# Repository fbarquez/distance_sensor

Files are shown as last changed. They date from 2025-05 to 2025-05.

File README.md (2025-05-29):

# Ultrasonic Distance Sensor System – Abstandssensor

## Usage Notice

This project was developed as part of the module “Information Technology / Networked Systems” in the Bachelor's program in Information and Communication Engineering.

- Repository is archived and read-only.
- Not licensed for reuse, redistribution, or modification.
- For demonstration and educational reference only.
- Licensed under **UNLICENSED**.

> Developed by **Fbarquez** - HTW Berlin, 2021

---

## About the Project

This project is a **microcontroller-based distance measuring system** designed to support social distancing during the COVID-19 pandemic. The sensor system detects nearby objects using **ultrasound technology** and triggers **visual and acoustic alerts** when the safety distance is not maintained.

> **Main goal:** Help individuals monitor and maintain the recommended 1.5–2 meters distance to prevent virus transmission.

---

## Media Preview

### [▶ Watch Demo Video](https://www.dropbox.com/scl/fi/pl3xh61fnlcbmjqz21ddf/Abstandssensor_video_FB.mp4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)

> A live demo showing the behavior of the sensor system in real conditions.

---

## Project Objectives

- Measure distances in real-time using the **HC-SR04 ultrasonic sensor**
- Visually indicate proximity using **LEDs** (green = safe, red = warning)
- Trigger **buzzer** alert when distance is dangerously short
- Display distance on a **20x4 LCD display**
- **Transmit data via Bluetooth** to a mobile app
- Provide a **portable, reliable, and affordable** prevention tool

---

## Hardware Overview

| Component | Description |
|---|---|
| PIC16F1936 | 8-bit microcontroller (main control unit) |
| LCD 20x4 | Visual distance output |
| HC-SR04 | Ultrasonic distance sensor |
| LEDs | Red (short), Green (safe) alerts |
| Buzzer | Audio alert for danger distance |
| HC-05 Bluetooth Module | Wireless transmission to Android |
| External Power Supply  | 5V regulated |

> Schematics and PCB were designed using **EAGLE** software.

---

## System Logic

```text
              +--------------------+
              |    Ultrasonic      |
              |     Sensor         |
              +--------+-----------+
                       |
             Measures Time of Echo
                       |
                       v
        +--------------+--------------+
        |     PIC16F1936 MCU          |
        | (Distance Calculation Logic)|
        +-------+----------+----------+
                |          |         
         +------v--+  +----v-----+ 
         |   LCD    |  | Bluetooth| --> Smartphone App
         +----------+  +----------+
             |
     +-------+--------+
     |      LEDs      |
     |   Buzzer Alarm |
     +----------------+
````

The MCU uses **Timer1** to measure the echo pulse from the sensor. Based on the measured time, it calculates distance using:

```
distance_cm = duration / 58
```

Depending on the result:

* **> 50 cm** → Green LED ON (safe)
* **30–50 cm** → Red LED ON (warning)
* **< 30 cm** → Red LED + Buzzer ON (danger)

---

## How It Works

1. **Startup**: LCD displays intro text → system initializes
2. **Sensor trigger**: Sends 10μs pulse to HC-SR04 TRIG
3. **Echo measured**: Timer1 starts on echo rise, stops on fall
4. **Distance calculation**: Converts time into cm
5. **LED + Buzzer logic**: Executes based on thresholds
6. **LCD display**: Shows distance in cm
7. **Bluetooth transmission**: Sends data to Android app

---

## Project Structure

```
Abstandsssensor.X/
├── main.c                   # Main program logic
├── lcd 20x4_1.h             # Custom LCD display driver
├── mcc_generated_files/     # Microchip Code Configurator auto-generated code
├── MyConfig.mc3             # MCC configuration file
├── nbproject/               # MPLAB X project configuration
├── Makefile                 # Project build rules
├── .clang-format            # Code formatting configuration
├── build/, dist/, debug/    # Build artifacts (can be ignored or gitignored)
├── eagle/
│   ├── Diseño .brd          # PCB layout
│   └── Diseño .sch          # Schematic diagram
```

---

## Features

* Real-time distance display on LCD
* Visual LED indication based on proximity
* Acoustic alarm for dangerous range
* Bluetooth communication with Android device
* Fully coded in C using **XC8** and **MPLAB X IDE**
* Clean code style with `.clang-format`
* Version-controlled with Git

---

## How to Build & Run

1. Open the project in **MPLAB X IDE**
2. Ensure you have:

   * XC8 compiler installed
   * MCC plugin enabled
3. Configure your hardware:

   * Connect HC-SR04 to RA0 (TRIG) and RA1 (ECHO)
   * Connect LEDs and Buzzer to PORTC
4. Program the PIC16F1936 using SNAP or PICKIT
5. Power on — the system is ready to operate

---

## Android App Integration

* The HC-05 Bluetooth module sends messages like:

  * `"DISTANCE: 045cm"`
  * `"ALARM: DANGEROUS"`
* App GUI made with **Bluetooth Electronics App**
* Enables real-time distance visualization on your phone

---

## Eagle Design Files

Schematic (`.sch`) and Board Layout (`.brd`) are included in the `eagle/` directory for PCB fabrication and review.

---

## Requirements

To build, program, or extend this project, you will need a set of development tools such as the MPLAB X IDE and the XC8 compiler.

Please refer to the [requirements.md](requirements.md) file for full details on the required software, versions, and links to official downloads.

---

## References

* [PIC16F1936 Datasheet](http://ww1.microchip.com/downloads/en/DeviceDoc/41364E.pdf)
* [HC-SR04 Datasheet](https://cdn.sparkfun.com/datasheets/Sensors/Proximity/HCSR04.pdf)
* [HC-05 Bluetooth](https://components101.com/sites/default/files/component_datasheet/HC-05)
* [HD44780 LCD](https://www.sparkfun.com/datasheets/LCD/HD44780.pdf)

---

For usage restrictions and legal information, see [NOTICE.md](NOTICE.md).

---

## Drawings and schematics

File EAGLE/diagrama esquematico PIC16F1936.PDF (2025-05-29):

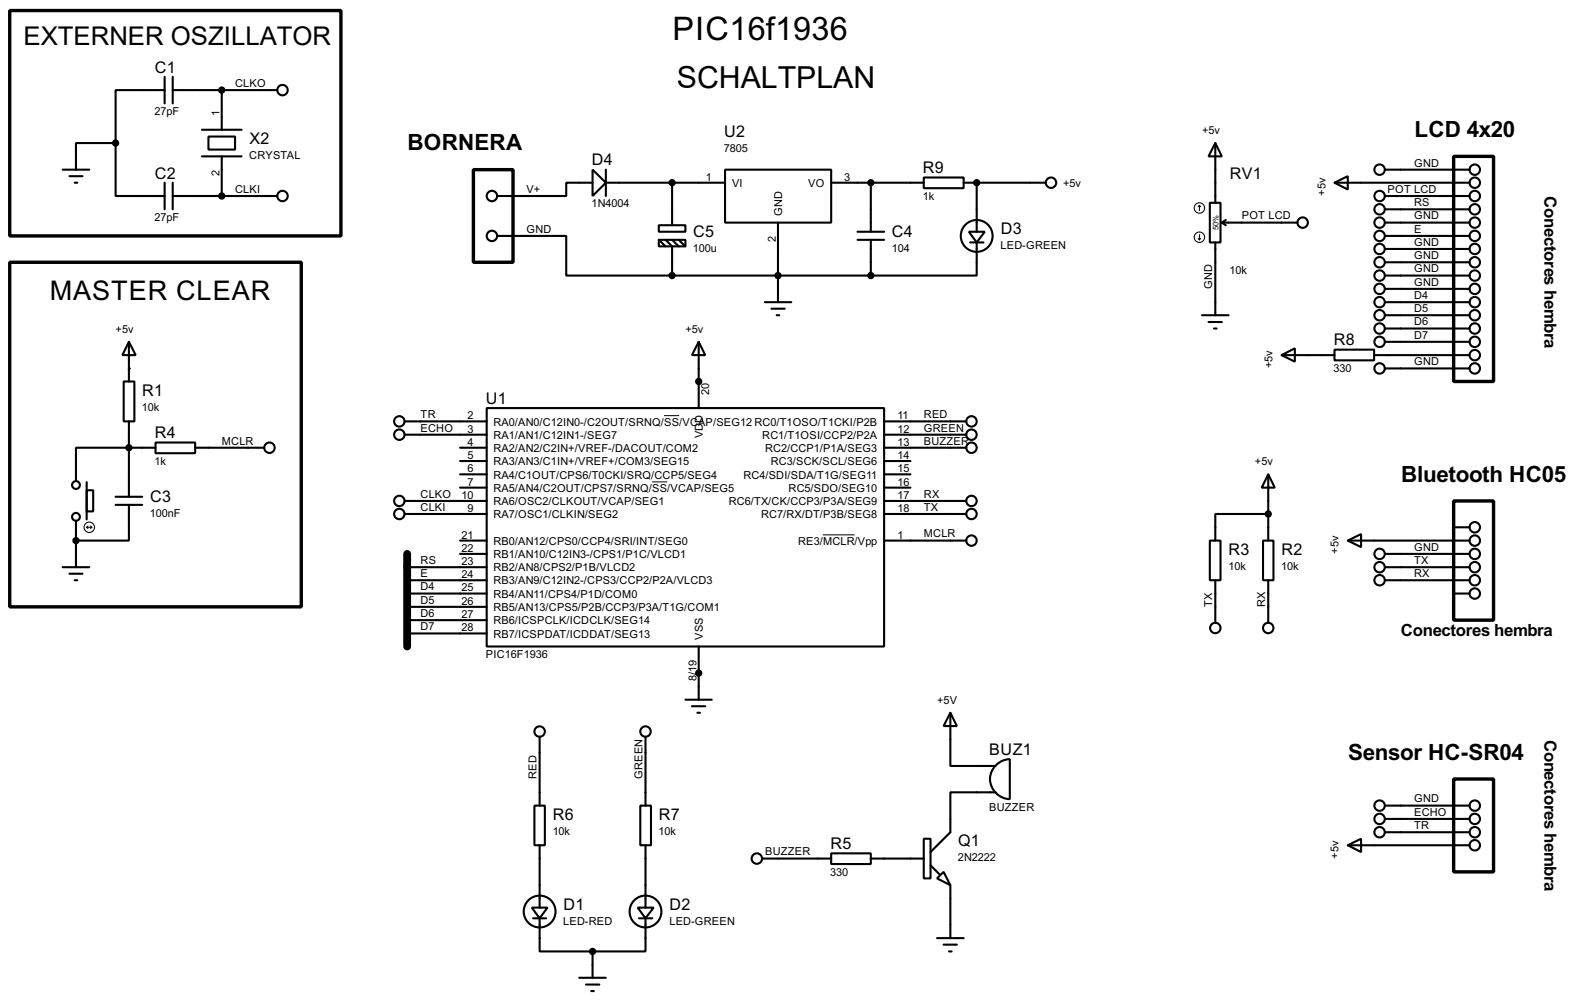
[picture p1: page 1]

PIC16f1936
SCHALTPLAN
Conectores hembraConectores hembra Conectores hembra
RSGND
EGND GND GND GND

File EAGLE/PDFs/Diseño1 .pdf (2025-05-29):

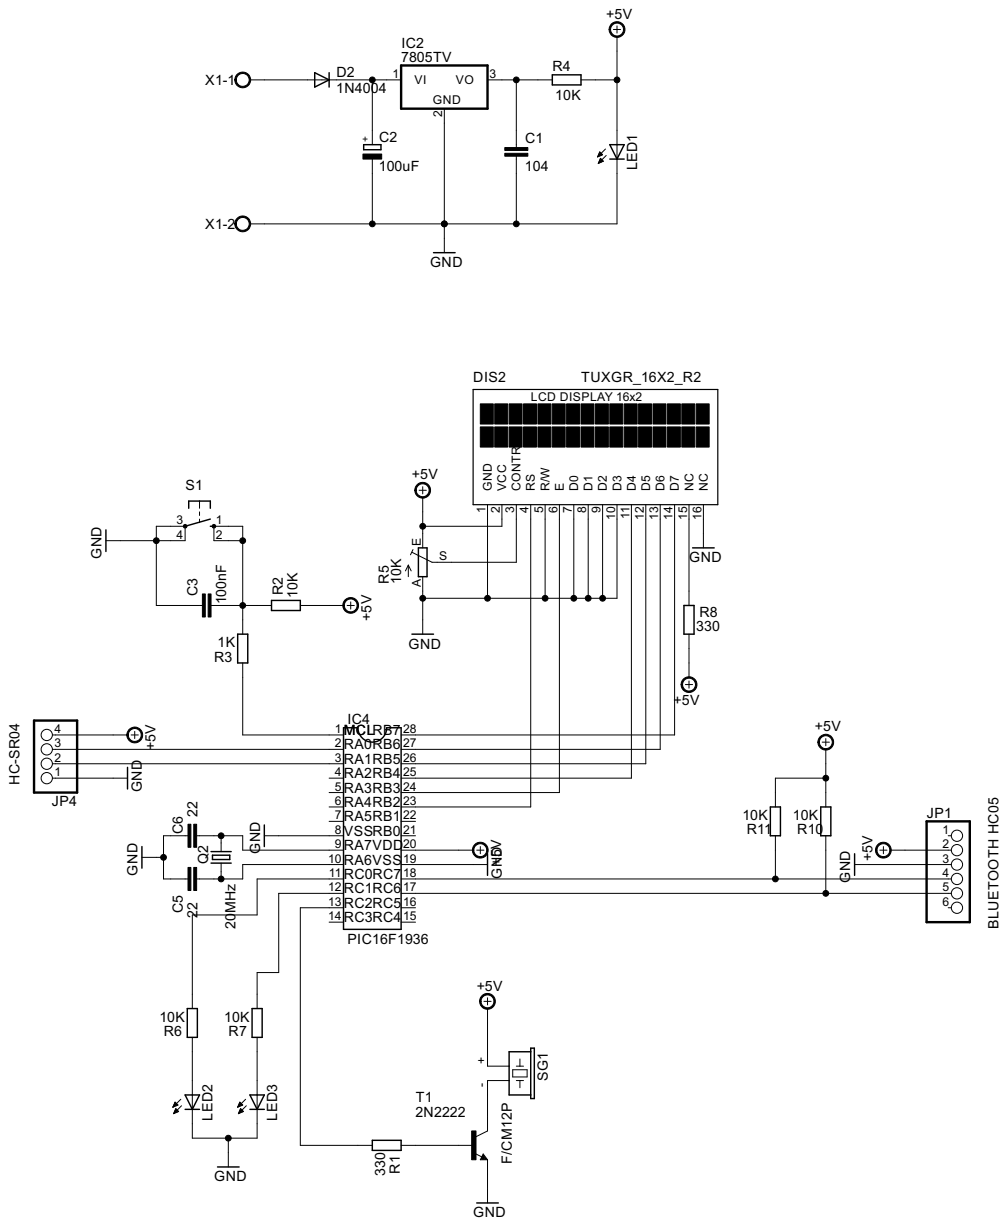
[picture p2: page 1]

27
26
25
24

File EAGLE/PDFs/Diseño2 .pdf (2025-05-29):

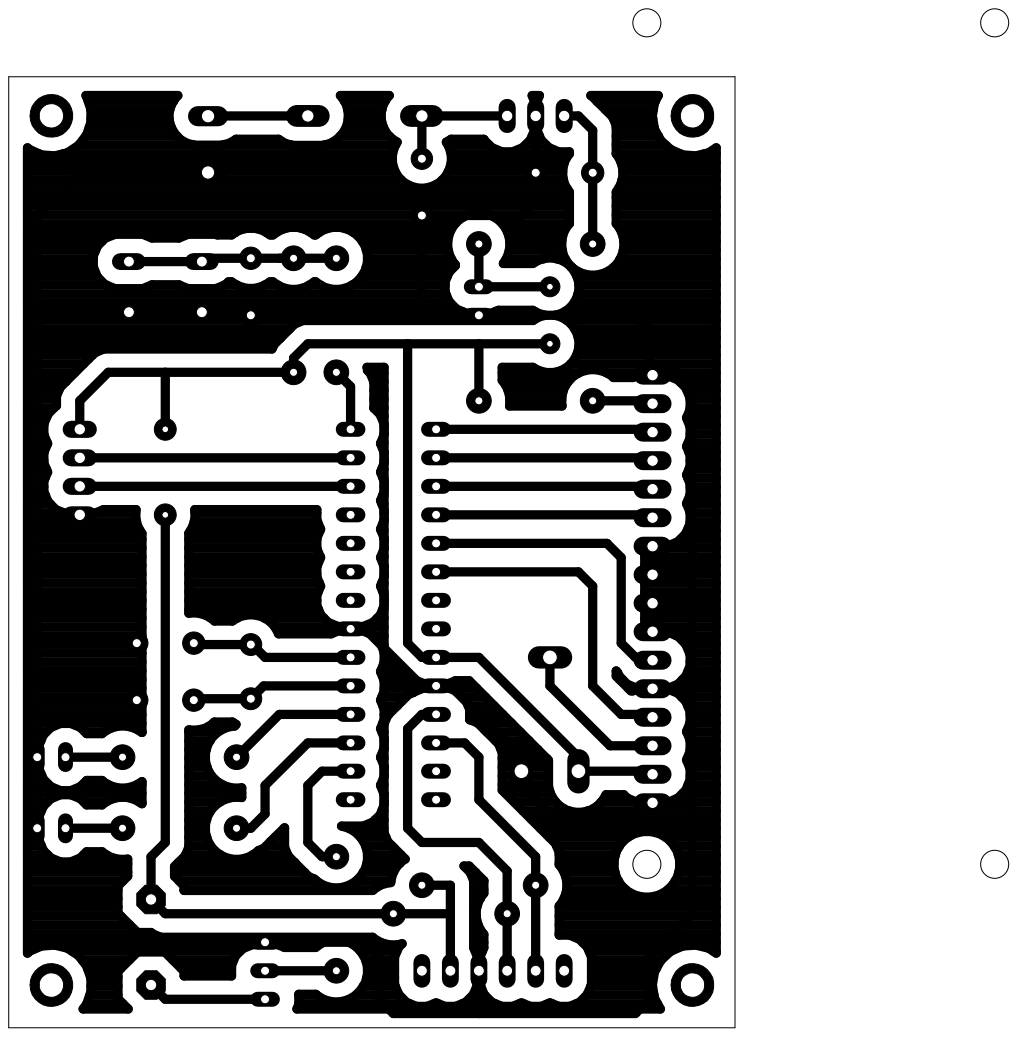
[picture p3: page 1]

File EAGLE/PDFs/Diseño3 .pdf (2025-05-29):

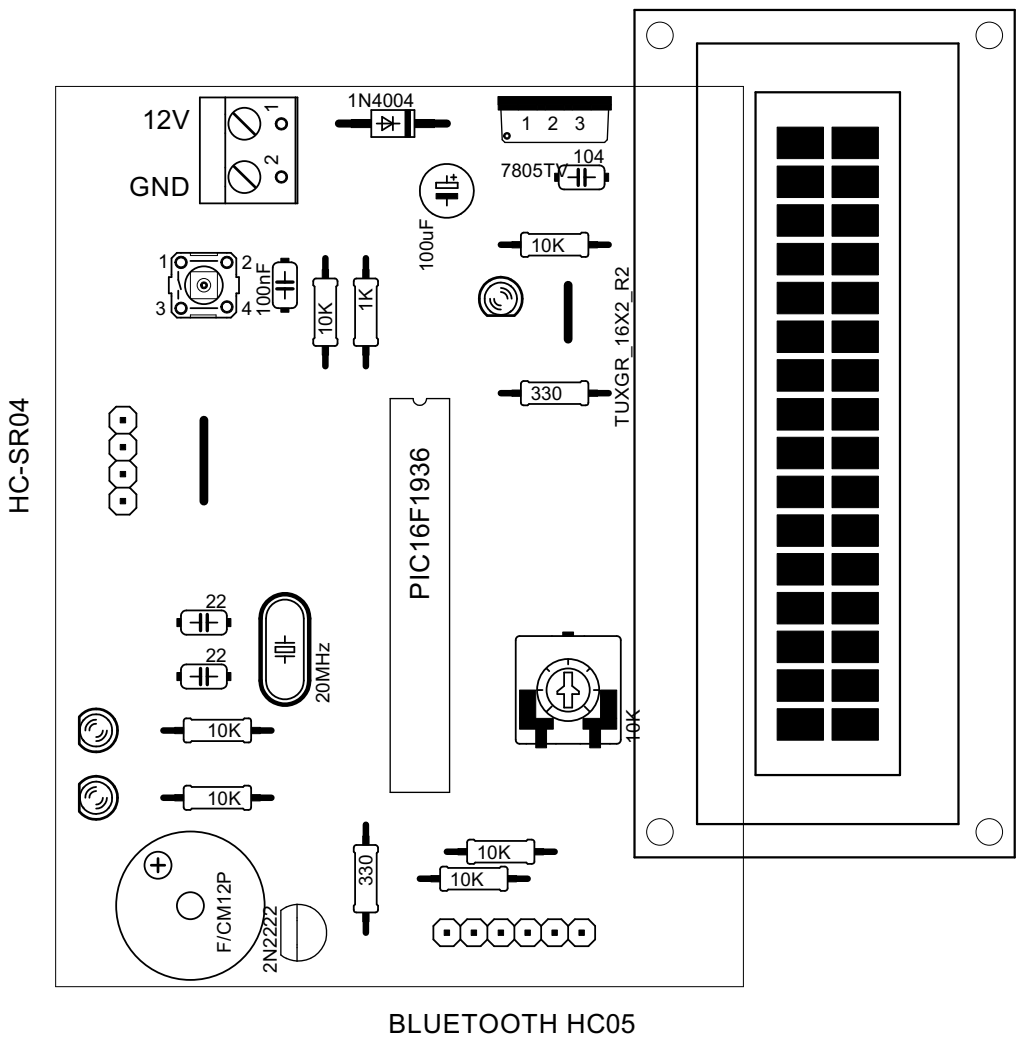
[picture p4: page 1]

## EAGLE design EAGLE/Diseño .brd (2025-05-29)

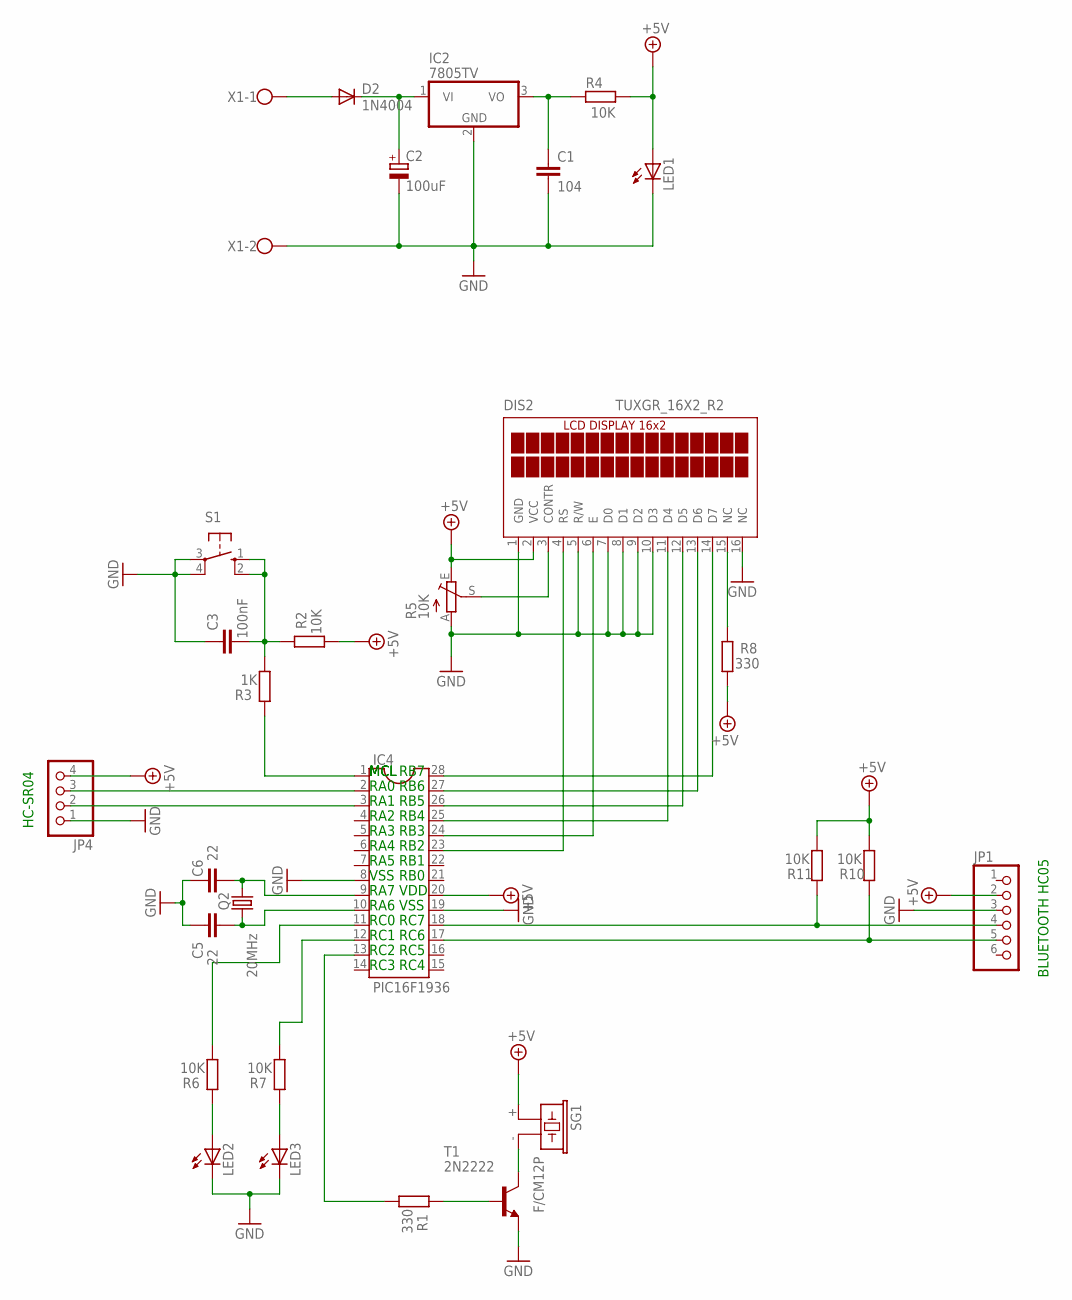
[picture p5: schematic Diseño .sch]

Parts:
C1: 104; C050-024X044
C2: 100uF; E5-5
C3: 100nF; C050-024X044
C5, C6: 22; C050-024X044
D2: 1N4004; DO41-10
DIS2: TUXGR_16X2_R2
IC2: 7805TV; TO220V
IC4: PIC16F1936; DIL28S
JP1: PINHD-1X6; 1X06
JP4: PINHD-1X4; 1X04
LED1, LED2, LED3: LED3MM
Q2: 20MHz; HC49U-V
R1, R8: 330; 0207/10
R2, R4, R6, R7, R10, R11: 10K; 0207/10
R3: 1K; 0207/10
R5: 10K; CA9V
S1: 10-XX; B3F-10XX
SG1: F/CM12P
T1: 2N2222; TO92-EBC
X1: W237-102

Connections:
+5V: DIS2.2 (VCC), IC4.20, JP1.2, JP4.4, LED1.A, R2.1, R4.1, R5.E, R8.1, R10.1, R11.1, SG1.+ (1)
GND: C1.2, C2.-, C3.2, C5.2, C6.2, DIS2.1 (GND), DIS2.5 (R/W), DIS2.7 (D0), DIS2.8 (D1), DIS2.9 (D2), DIS2.10 (D3), DIS2.16 (NC), IC2.2 (GND), IC4.8, IC4.19, JP1.3, JP4.1, LED1.K (C), LED2.K (C), LED3.K (C), R5.A, S1.3, S1.4 (P1), T1.E, X1.2
unnamed: D2.A, X1.1
unnamed: IC4.1, R3.2
unnamed: R1.2, T1.B
unnamed: SG1.- (2), T1.C
unnamed: C3.1, R2.2, R3.1, S1.1 (S), S1.2 (S1)
unnamed: IC4.13, R1.1
unnamed: IC4.2, JP4.3
unnamed: DIS2.15 (NC), R8.2
unnamed: IC4.18, JP1.4, R11.2
unnamed: IC4.17, JP1.5, R10.2
unnamed: DIS2.11 (D4), IC4.25
unnamed: DIS2.12 (D5), IC4.26
unnamed: IC4.3, JP4.2
unnamed: LED2.A, R6.2
unnamed: DIS2.13 (D6), IC4.27
unnamed: DIS2.14 (D7), IC4.28
unnamed: DIS2.6 (E), IC4.24
unnamed: C5.1, IC4.10, Q2.1
unnamed: C6.1, IC4.9, Q2.2
unnamed: DIS2.4 (RS), IC4.23
unnamed: C2.+, D2.C, IC2.1 (VI)
unnamed: C1.1, IC2.3 (VO), R4.2
unnamed: LED3.A, R7.2
unnamed: IC4.11, R6.1
unnamed: IC4.12, R7.1
unnamed: DIS2.3 (CONTR), R5.S

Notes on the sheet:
BLUETOOTH HC05
MCL
RA0
RA1
RA2
RA3
RA4
RA5
VSS
RA7
RA6
RC0
RC1
RC2
RC3
RC4
RC5
RC6
RC7
VDD
RB0
RB1
RB2
RB3
RB4
RB5
RB6
RB7
HC-SR04

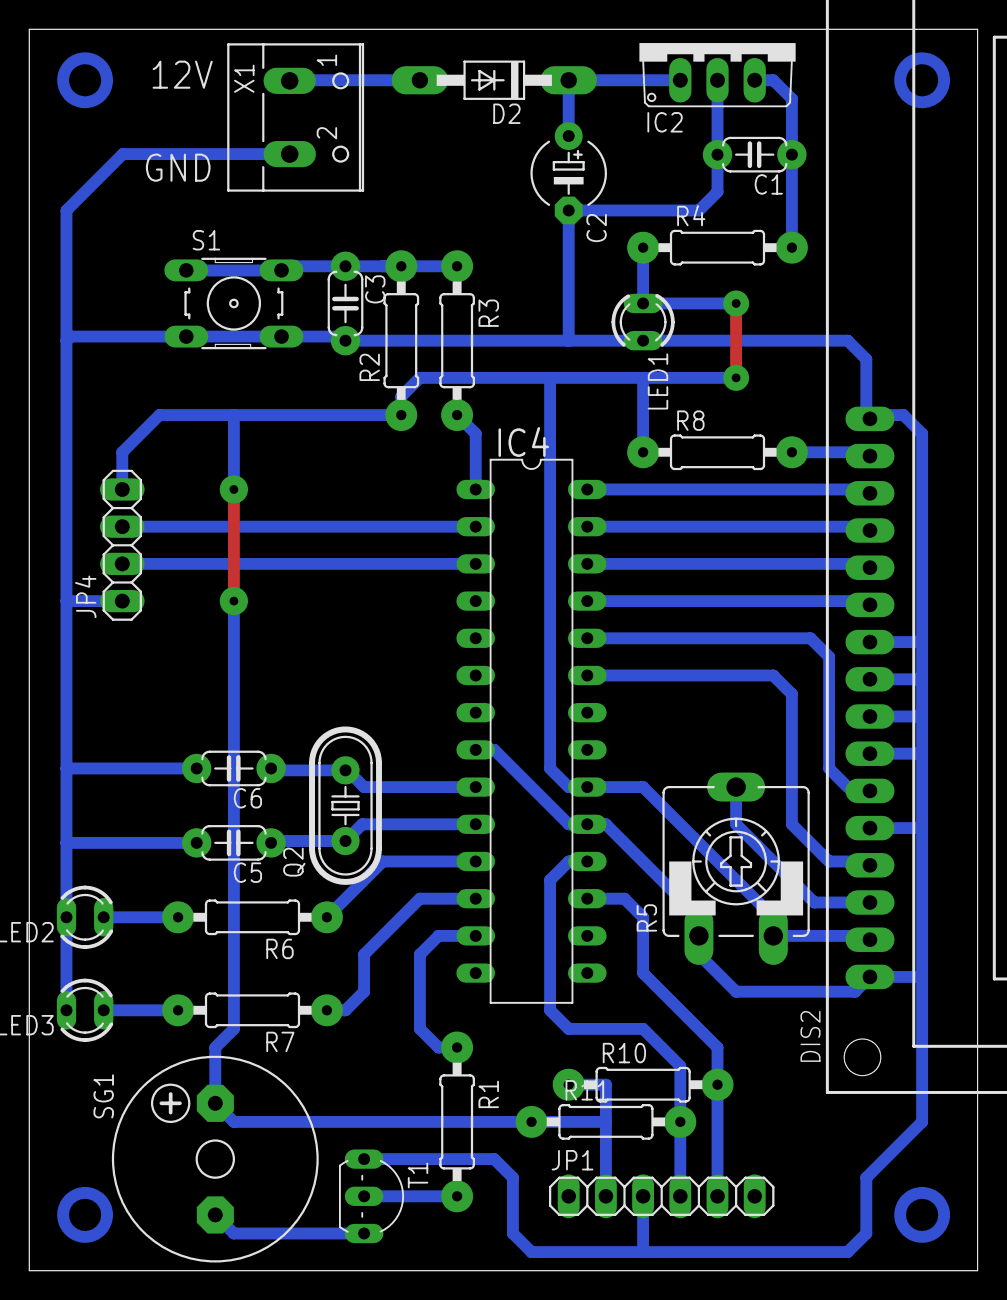
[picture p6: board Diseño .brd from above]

Board: 2 copper layers, 64.8 x 84.8 mm, 29 parts (0 on the bottom side), 28 nets.

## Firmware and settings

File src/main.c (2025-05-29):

/*********************************************************************************
 ********************** Distance Sensor/Abstandssensor **************************
 *********************************by Fbarquez***********************************
 ******************************************************************************/

#include <stdio.h>
#include <stdlib.h>

#include "lcd 20x4_1.h"  // Die Bibliothek 4x20 LCD ist enthalten. Das Display wird an Port B angeschlossen.
#include "mcc_generated_files/mcc.h"

#define PinEcho PORTAbits.RA1     // Pin RA1 ist mit dem Echo-Pin verbunden. (digitaler Eingang)
#define PinTrig LATAbits.LATA0    // Pin RA0 ist mit Pin Trig. (digitaler Ausgang)
#define Led_Red LATCbits.LATC0    // Der Pin RC0 ist der roten LED zugewiesen.
#define Led_Green LATCbits.LATC1  // Der Pin RC1 ist der grünen LED zugewiesen.
#define Buzzer LATCbits.LATC2     // Der Pin RC2 ist dem Buzzer zugewiesen.
#define HIGH 1                    // Hohes Niveau
#define LOW 0                     // Niedriges Niveau.

// Globale Variablen für erweiterte Funktionalitäten
float Velocidad_Sonido = 34000.0;  // Geschwindigkeit des Schalls.
float Distancia        = 0.0;      // Variable vom Typ Fließkomma 32 Bit
float Tiempo           = 0.0;      // Variable vom Typ Fließkomma 32 Bit für die Zeit.
float Temperatura =
    0.0;  // Variable vom Typ 32 Bit Float, hier wird der Temperaturwert gespeichert.
float Humedad =
    0.0;  // Variable vom Typ 32 Bit Float, in der der Feuchtigkeitswert gespeichert wird.

char Buffer[20] = " ";      // Einrichtung zum Speichern der Variablen, die über die serielle
                            // Kommunikation gesendet werden.
char     LCD_Buffer[20];    // Einrichtung für die Anzeige der Variablen auf dem 4x20 LCD Display.
uint16_t Lecturas[10];      // Einrichtung für 10 Leseelemente.
volatile char Caracter_RX;  // Die Variable "Caracter_RX" muss flüchtig sein, da ihr Wert in sie
                            // geladen wird von der Interrupt Funktion.
volatile uint8_t Buffer_RX[20];
volatile uint8_t Contador_RX;

void         Timer1_Init(void);       // Funktion zur Initialisierung von Timer 1.
unsigned int ObtenerDistancia(void);  // Funktion zur Ermittlung des Abstands (der Entfernung).

void main(void)
{
    unsigned int distancia;  // Variable Abstand.

    // Nicht verwendete, aber vorbereitete Variablen für spätere Funktionserweiterung:
    // unsigned int anterior;        // Vorherige Variable.
    // unsigned int dismax;          // Variable dis_max. (maximaler Abstand).
    // unsigned int dismin;          // Variable dis_min. (kleinster Abstand).

    SYSTEM_Initialize();  // Systeminitialisierung.
    ANSELA = 0x00;        // Wir deaktivieren die analogen Eingänge von Anschluss A.
    ANSELB = 0x00;        // Wir deaktivieren die analogen Eingänge von Anschluss B.
    TRISA &= ~(1 << 0);   // Wir konfigurieren den Pin RA0 als digitalen Ausgang.
    TRISA |= (1 << 1);    // Wir konfigurieren den Pin RA1 als digitalen Eingang.
    TRISC = 0x00;         // Wir konfigurieren den Port C als digitalen Ausgang.
    LATC  = 0x00;         // Der Port C wird anfangs auf "low" gesetzt.
    Timer1_Init();        // Wir rufen die Startfunktion von Timer1 auf.
    LCD_Init();           // Wir initialisieren die 4x20 LCD-Display.

    LCD_gotoxy_putc(1, 1,
                    "   PROJEKT IT/VS    ");  // Auf dem 4x20 LCD Display wird ein Text angezeigt.
    LCD_gotoxy_putc(2, 1,
                    "     PIC16F1936     ");  // Auf dem 4x20 LCD Display wird ein Text angezeigt.
    LCD_gotoxy_putc(3, 1,
                    "Fernando Barriga Vas");  // Auf dem 4x20 LCD Display wird ein Text angezeigt.
    __delay_ms(5000);                         // Eine Verzögerung von 5s.

    while (1)
    {
        distancia = ObtenerDistancia();  // Die Variable distancia=al valor, der von der Funktion
                                         // "ObtenerDistancia" zurückgegeben wird.

        sprintf(LCD_Buffer, "   DISTANCE: %03ucm", distancia);  // Wert in LCD-Puffer schreiben.
        LCD_gotoxy_putc(3, 1, LCD_Buffer);                      // Abstand auf dem LCD anzeigen.

        printf("G%03u, distancia\n", distancia);  // Abstand an die serielle Schnittstelle senden.
        printf("T%03u, distancia\n", distancia);  // Abstand an die serielle Schnittstelle senden.

        if (distancia <= 50 && distancia >= 30)
        {
            LCD_gotoxy_putc(
                1, 1,
                "********ALARM*******");  // Auf dem 4x20 LCD Display wird eine Nachricht angezeigt.
            LCD_gotoxy_putc(
                2, 1,
                "   SHORT DISTANCE   ");  // Auf dem 4x20 LCD Display wird eine Nachricht angezeigt.
            LCD_gotoxy_putc(
                4, 1,
                "     LED RED ON     ");  // Auf dem 4x20 LCD Display wird eine Nachricht angezeigt.
            Led_Red   = HIGH;             // Rote LED an.
            Led_Green = LOW;              // Grüne LED ist aus.
            Buzzer    = LOW;              // Buzzer aus.
            printf("NR0G0B0\n");
            printf("LR255G0B0\n");
            printf("MR0G0B0\n");
            printf("ALARM\n");
            printf("SHORT DISTANCE\n");
            printf("DISTANCE: %s\n", LCD_Buffer);  // Abstand erneut anzeigen.
            __delay_ms(100);
            printf("\f");
        }
        else if (distancia < 30)
        {
            LCD_gotoxy_putc(
                1, 1,
                "********ALARM*******");  // Auf dem 4x20 LCD Display wird eine Nachricht angezeigt.
            LCD_gotoxy_putc(
                2, 1,
                " DANGEROUS DISTANCE ");  // Auf dem 4x20 LCD Display wird eine Nachricht angezeigt.
            LCD_gotoxy_putc(
                4, 1,
                " BUZZER--LED RED ON ");  // Auf dem 4x20 LCD Display wird eine Nachricht angezeigt.
            Led_Red   = HIGH;             // Rote LED an.
            Led_Green = LOW;              // Grüne LED ist aus.
            Buzzer    = HIGH;             // Buzzer an.
            printf("LR255G0B0\n");
            printf("MR255G233B0\n");
            printf("NR0G0B0\n");
        }
        else if (distancia > 50)
        {
            LCD_gotoxy_putc(
                1, 1,
                "      NO ALARMS     ");  // Auf dem 4x20 LCD Display wird eine Nachricht angezeigt.
            LCD_gotoxy_putc(
                2, 1,
                "    OUT OF RANGE    ");  // Auf dem 4x20 LCD Display wird eine Nachricht angezeigt.
            LCD_gotoxy_putc(
                4, 1,
                "    LED GREEN ON    ");  // Auf dem 4x20 LCD Display wird eine Nachricht angezeigt.
            Led_Red   = LOW;              // Rote LED aus.
            Led_Green = HIGH;             // Grüne LED an.
            Buzzer    = LOW;              // Buzzer aus.
            printf("NR0G255B0\n");
            printf("LR0G0B0\n");
            printf("MR0G0B0\n");
        }

        __delay_ms(100);
    }
}

void Timer1_Init(void)  // Startfunktion Timer1.
{
    T1CONbits.TMR1CS = 0b00;  // Der Taktgeber von Timer1 muss Fosc/4 sein.
    T1CONbits.T1CKPS = 0b00;  // Der Pre-Scaler von Timer1 wird auf 1 gesetzt.
    T1CONbits.TMR1ON = 0;     // Timer 1 wird angehalten.
    TMR1             = 0;     // Counter von Timer1 ist gleich 0
}

unsigned int ObtenerDistancia(void)
{
    uint16_t duracion;
    uint16_t distancia;
    uint16_t Timer1;

    PinTrig = 1;
    __delay_us(10);
    PinTrig = 0;

    while (PinEcho == 0);
    T1CONbits.TMR1ON = 1;
    while (PinEcho == 1);
    T1CONbits.TMR1ON = 0;

    Timer1   = TMR1;
    duracion = Timer1;

    if (duracion < 116)
        distancia = 0;
    else if (duracion <= 23200)
        distancia = duracion / 58;
    else
        distancia = 0;

    duracion = 0;
    TMR1     = 0;

    return distancia;
}

/**
 End of File
*/
